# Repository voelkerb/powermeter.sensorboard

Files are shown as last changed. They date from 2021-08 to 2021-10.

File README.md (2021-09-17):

[PowerMeter]: (https://github.com/voelkerb/powermeter)
[bopla]:(https://www.conrad.de/de/p/bopla-eletec-se-432-de-cee-stecker-gehaeuse-120-x-65-x-50-abs-polycarbonat-lichtgrau-graphitgrau-1-st-522228.html)

# powermeter.sensorboard
Expansion board for the [PowerMeter] including multiple environmental sensors, LEDs, and a push button.

The [PowerMeter] includes an extension header that exposes the ESP32's UART interface.
This interface can be used to add more environmental sensors to a [PowerMeter].
The developed sensor board can be stacked on the [PowerMeter] _PCB_ and the embedded sensors may be exposed to the outside of the housing. 
See the following example:

<p align="center">
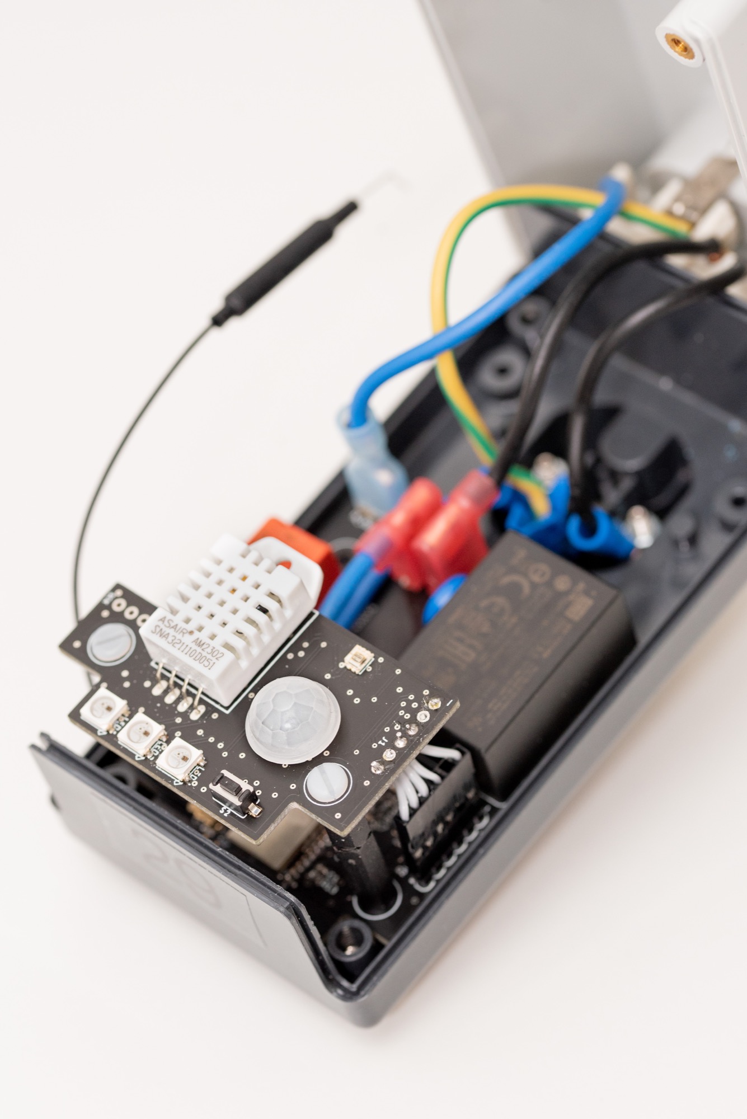
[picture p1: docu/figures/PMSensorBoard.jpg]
  
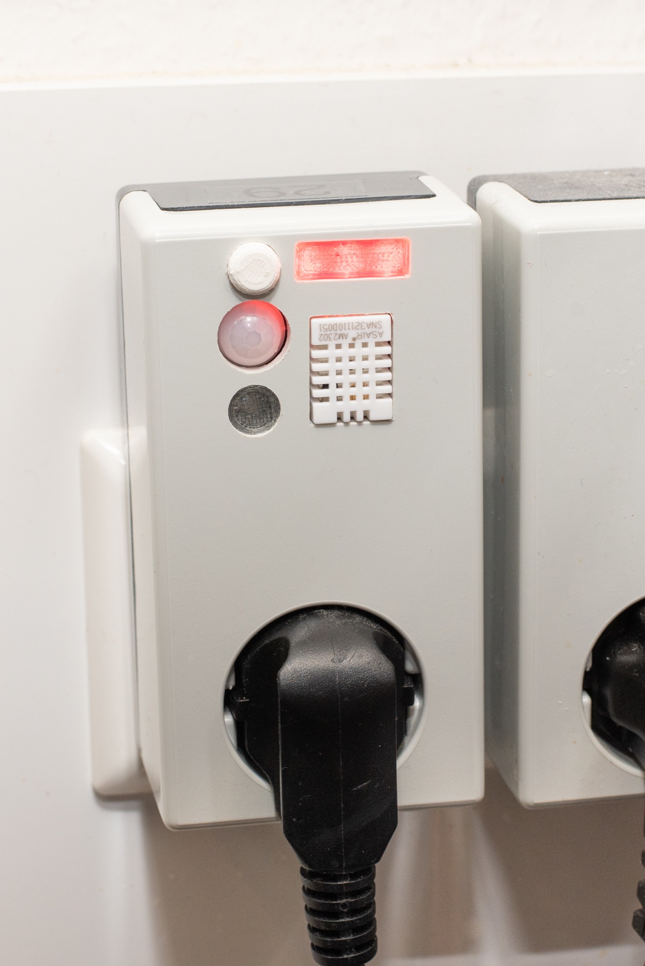
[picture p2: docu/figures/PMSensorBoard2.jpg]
  
</p>

---

## Sensors
The board incorporates typical environmental sensors:
A DHT22 for temperature and humidity readings, a TSL2561 light sensor and PIR sensor to detect people's movements. 

## Feedback
For visual feedback, three WS2812B RGB LEDs are included. These can automatically visualize the current energy consumption via color (_eco-feedback_) or indicate states or errors via patterns.   

## Interfacing
The incorporated button allows to switch the [PowerMeter] relay. If you require other functionality, these can be added via double-press or long-press gestures as well.

## Housing
The housing is a modified version of the [bopla] housing used for the [PowerMeter]. You can either cut in holes or 3D print a version with corresponding cutouts and holders for the sensor board. The 3D files also include the button and a light sensor and LED cover which should be printed with transparent filament.

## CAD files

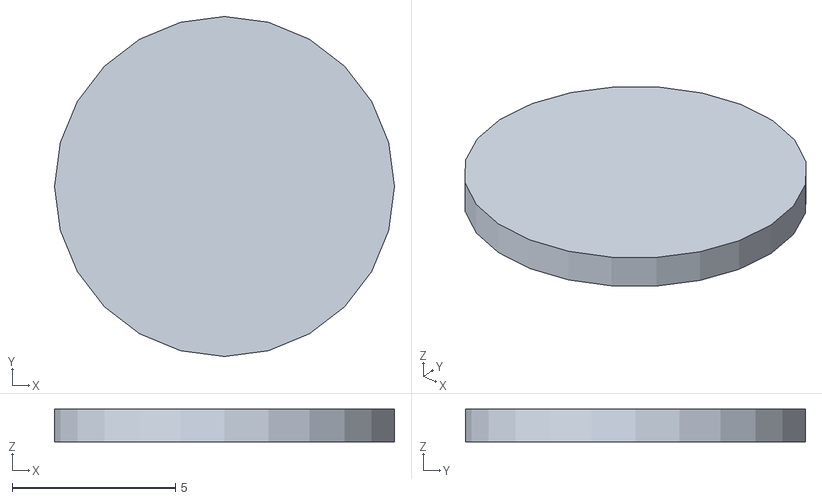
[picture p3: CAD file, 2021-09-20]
CAD/coverLight.stl
10.4 x 10.4 x 1

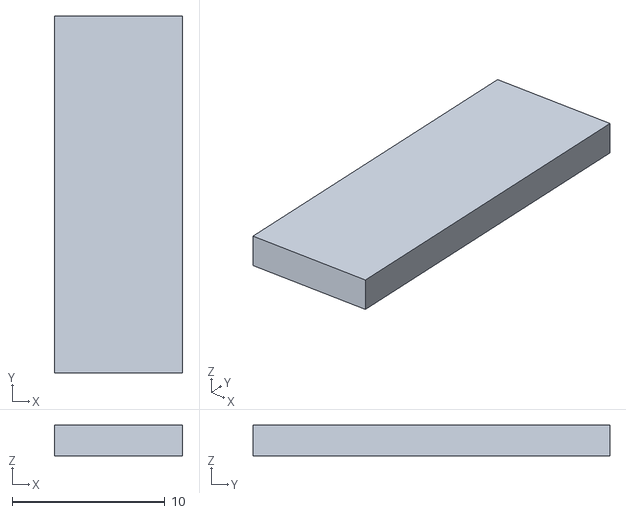
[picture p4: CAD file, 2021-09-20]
CAD/coverLED.stl
8.40 x 23.4 x 2.00

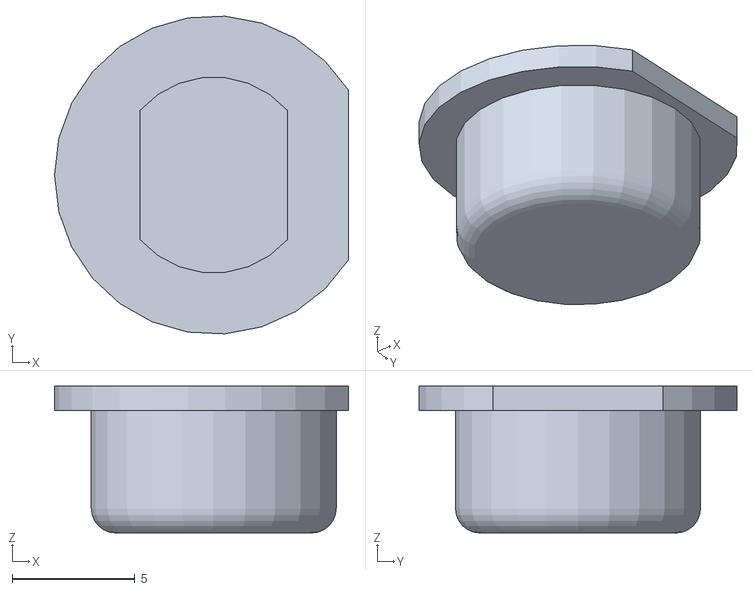
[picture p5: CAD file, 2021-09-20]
CAD/button.stl
12.0 x 13.0 x 6.00

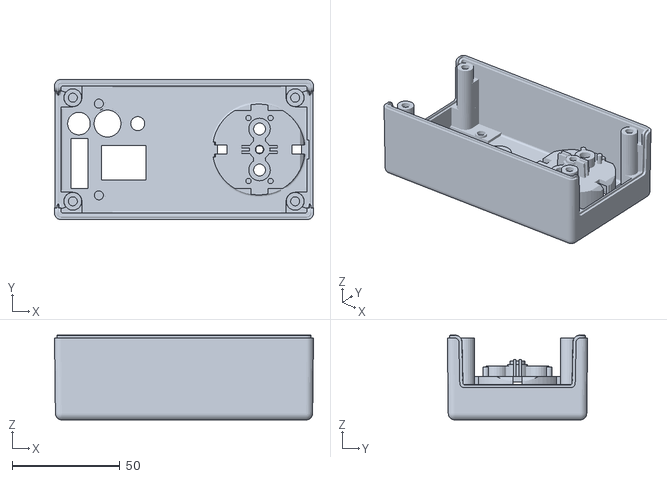
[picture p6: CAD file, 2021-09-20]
CAD/housingTop.stl
120.0 x 65.0 x 39.3

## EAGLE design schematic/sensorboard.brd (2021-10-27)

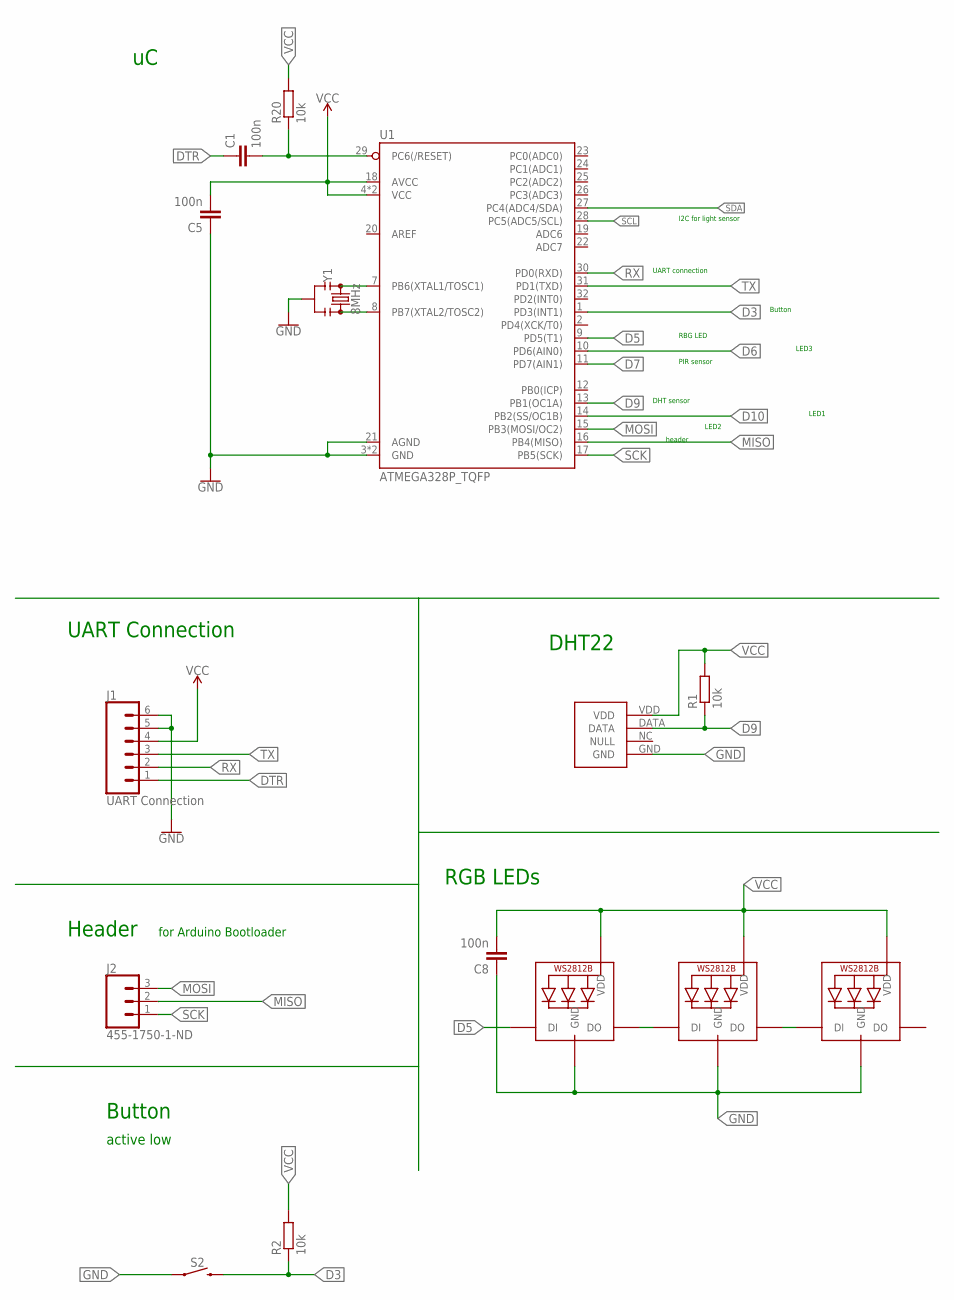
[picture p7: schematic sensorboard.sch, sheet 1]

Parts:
C1, C5, C8: 100n; C0402
DHT22: DHT22
J1: UART Connection; 1X06
J2: 455-1750-1-ND; 1X03
LED1, LED2, LED3: WS2812B5050; WS2812B
R1, R2, R20: 10k; R0402
S2: MOMENTARY-SWITCH-SPST-SMD-6.0X3.5MM; TACTILE_SWITCH_SMD_6.0X3.5MM
U1: ATMEGA328P_TQFP; TQFP32-08
Y1: 8MHz; RESONATOR-SMD-3.2X1.3

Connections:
D3: R2.1, S2.2, U1.1 (PD3(INT1))
D5: LED2.4-DIN (DI), U1.9 (PD5(T1))
D6: U1.10 (PD6(AIN0)); also elsewhere on the board
D7: U1.11 (PD7(AIN1)); also elsewhere on the board
D9: DHT22.DATA, R1.1, U1.13 (PB1(OC1A))
D10: U1.14 (PB2(SS/OC1B)); also elsewhere on the board
DTR: C1.1, J1.1
GND: C5.1, C8.1, DHT22.GND, J1.5, J1.6, LED1.3-GND (GND), LED2.3-GND (GND), LED3.3-GND (GND), S2.1, U1.3 (GND), U1.5 (GND), U1.21 (AGND), Y1.2; also elsewhere on the board
MISO: J2.2, U1.16 (PB4(MISO))
MOSI: J2.3, U1.15 (PB3(MOSI/OC2)); also elsewhere on the board
unnamed: U1.7 (PB6(XTAL1/TOSC1)), Y1.1
unnamed: U1.8 (PB7(XTAL2/TOSC2)), Y1.3
unnamed: LED1.4-DIN (DI), LED2.2-DOUT (DO)
unnamed: LED1.2-DOUT (DO), LED3.4-DIN (DI)
unnamed: C1.2, R20.1, U1.29 (PC6(/RESET))
RX: J1.2, U1.30 (PD0(RXD))
SCK: J2.1, U1.17 (PB5(SCK))
SCL: U1.28 (PC5(ADC5/SCL)); also elsewhere on the board
SDA: U1.27 (PC4(ADC4/SDA)); also elsewhere on the board
TX: J1.3, U1.31 (PD1(TXD))
VCC: C5.2, C8.2, DHT22.VDD, J1.4, LED1.1-VDD (VDD), LED2.1-VDD (VDD), LED3.1-VDD (VDD), R1.2, R2.2, R20.2, U1.4 (VCC), U1.6 (VCC), U1.18 (AVCC); also elsewhere on the board

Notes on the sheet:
DHT22
UART Connection
Button
DHT sensor
I2C for light sensor
PIR sensor
active low
Header
for Arduino Bootloader
LED1
LED2
LED3
UART connection
header
RBG LED
RGB LEDs

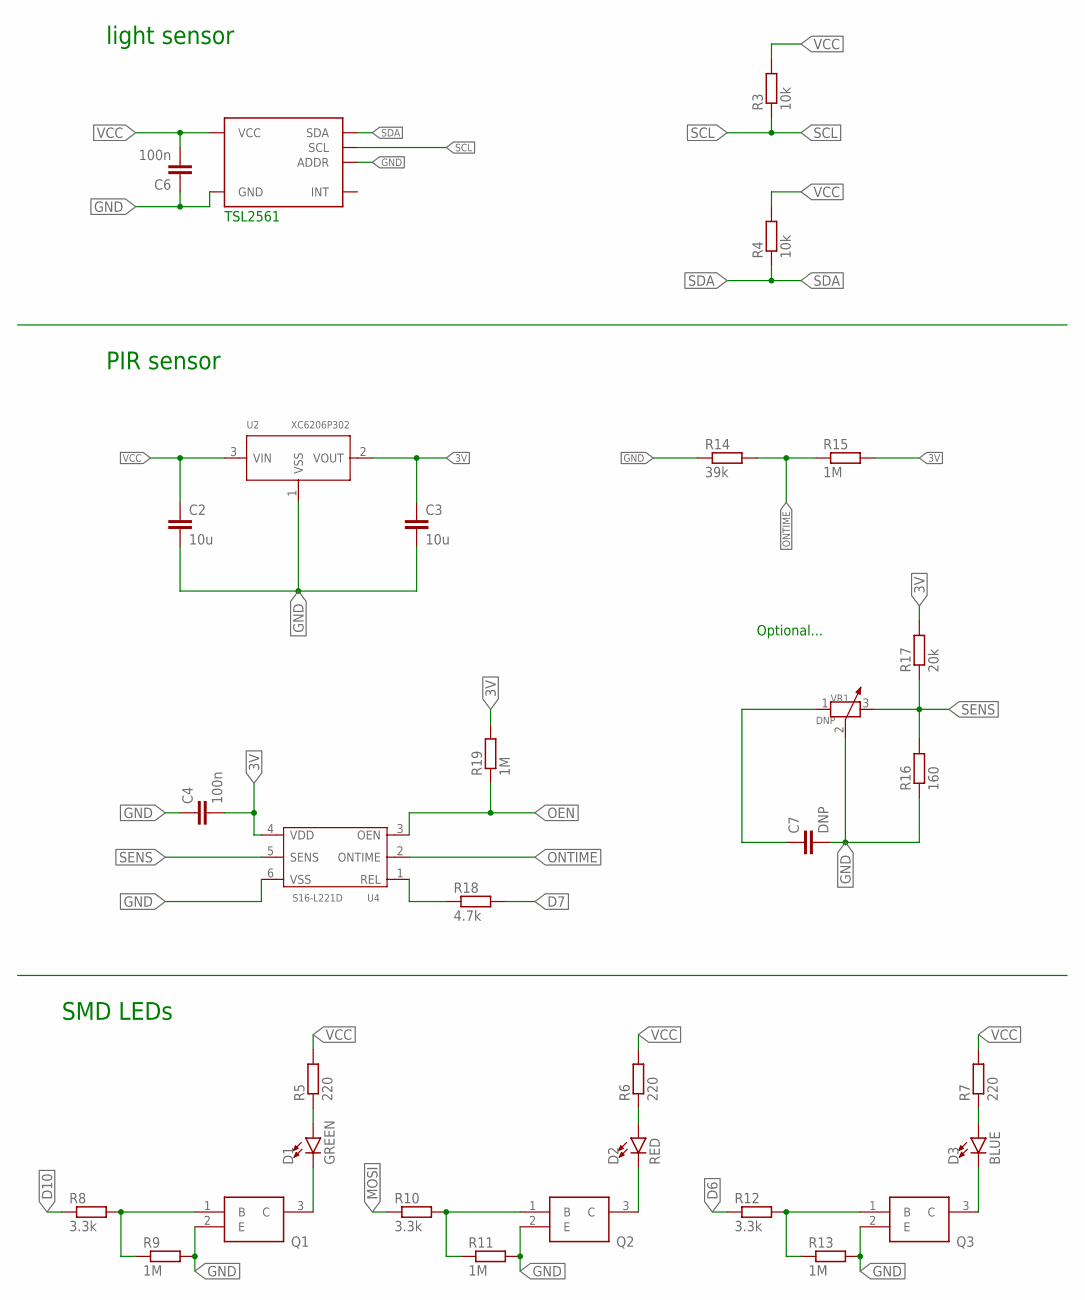
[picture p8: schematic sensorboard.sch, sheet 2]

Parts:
C2, C3: 10u; C0402
C4, C6: 100n; C0402
C7: DNP; C0402
D1: GREEN; LED-0603
D2: RED; LED-0603
D3: BLUE; LED-0603
Q1, Q2, Q3: MMSS8050-L-TP; SOT96P237X122-3N
R3, R4: 10k; R0402
R5, R6, R7: 220; R0402
R8, R10, R12: 3.3k; R0402
R9, R11, R13, R15, R19: 1M; R0402
R14: 39k; R0402
R16: 160; R0402
R17: 20k; R0402
R18: 4.7k; R0402
TSL2561: TSL2561FN; DFN-6
U2: XC6206P302; SOT-23
U4: S16-L221D; 6P-SMD-6X6MM
VR1: DNP; ADJR3-SMD-4.6X3.7MM

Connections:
3V: C3.1, C4.2, R15.2, R17.2, R19.2, U2.2 (VOUT), U4.4 (VDD)
D6: R12.1; also elsewhere on the board
D7: R18.2; also elsewhere on the board
D10: R8.1; also elsewhere on the board
GND: C2.2, C3.2, C4.1, C6.1, C7.2, Q1.2 (E), Q2.2 (E), Q3.2 (E), R9.2, R11.2, R13.2, R14.1, R16.1, TSL2561.ADDR, TSL2561.GND, U2.1 (VSS), U4.6 (VSS), VR1.2 (3); also elsewhere on the board
MOSI: R10.1; also elsewhere on the board
unnamed: R18.1, U4.1 (REL)
unnamed: C7.1, VR1.1
unnamed: D1.C, Q1.3 (C)
unnamed: Q1.1 (B), R8.2, R9.1
unnamed: Q2.1 (B), R10.2, R11.1
unnamed: Q3.1 (B), R12.2, R13.1
unnamed: D1.A, R5.1
unnamed: D2.C, Q2.3 (C)
unnamed: D2.A, R6.1
unnamed: D3.A, R7.1
unnamed: D3.C, Q3.3 (C)
OEN: R19.1, U4.3 (OEN)
ONTIME: R14.2, R15.1, U4.2 (ONTIME)
SCL: R3.1, TSL2561.SCL; also elsewhere on the board
SDA: R4.1, TSL2561.SDA; also elsewhere on the board
SENS: R16.2, R17.1, U4.5 (SENS), VR1.3 (2)
VCC: C2.1, C6.2, R3.2, R4.2, R5.2, R6.2, R7.2, TSL2561.VDD (VCC), U2.3 (VIN); also elsewhere on the board

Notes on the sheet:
light sensor
PIR sensor
TSL2561
Optional...
SMD LEDs

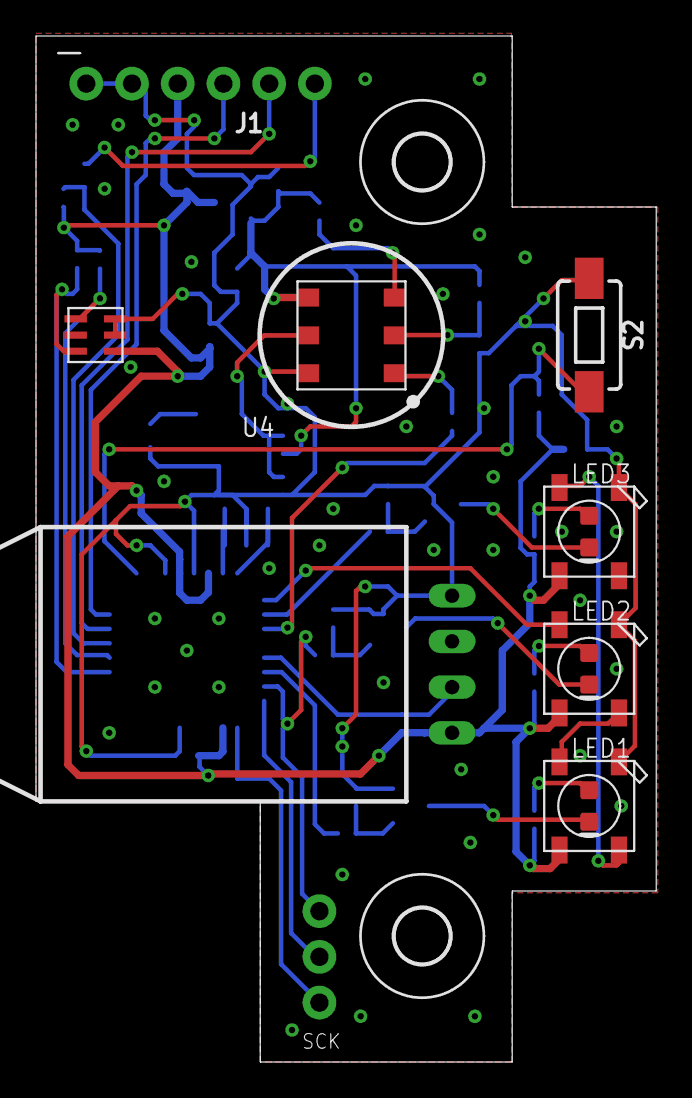
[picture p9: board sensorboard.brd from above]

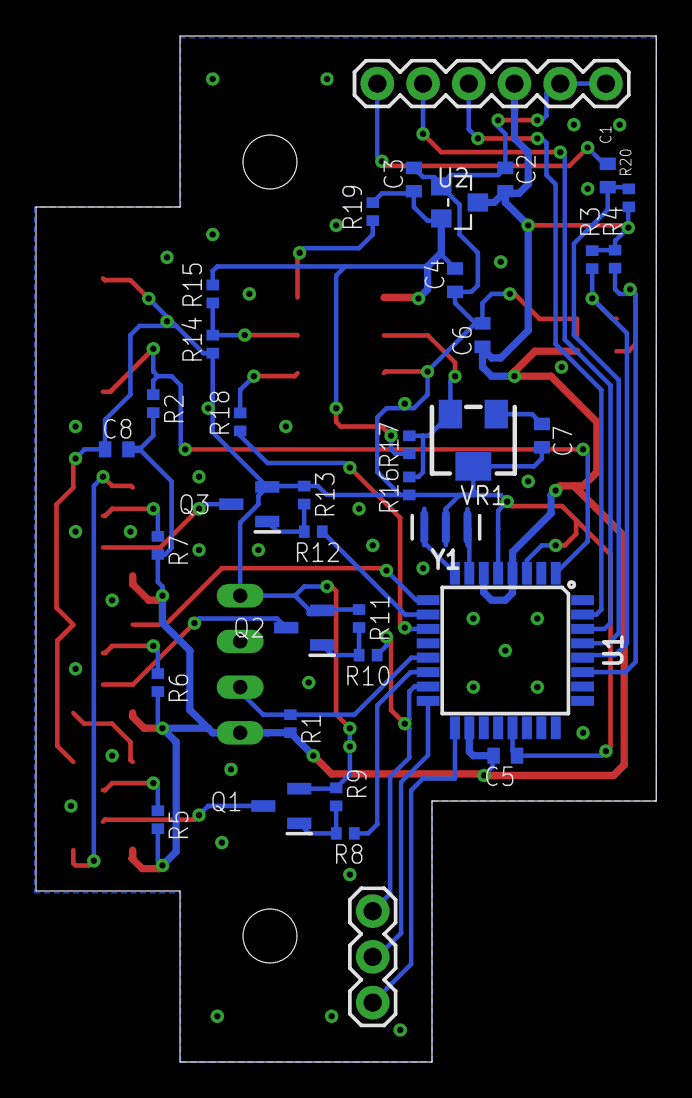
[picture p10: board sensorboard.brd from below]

Board: 2 copper layers, 34.5 x 57.0 mm, 49 parts (37 on the bottom side), 36 nets.

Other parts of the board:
U$1, U$2: 3,0

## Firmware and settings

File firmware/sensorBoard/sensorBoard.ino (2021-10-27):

// Arduino ATMEGA328 8MHz Sketch with Sensors: DHT 11, Grove Button, LED WS2812b Light Sensor and PIR Sensor

// #include <ArduinoJson.h>
// #include <stdio.h>
// #include <string>

// sensor libraries
#include <FastLED.h>
#include <DHT.h>
#include <Wire.h>
#include <Digital_Light_TSL2561.h>
#include <SoftwareSerial.h>
#include <EEPROM.h>

// Choose one of the following
// Either you get press and release 
// #define STATEFULL_PRESS
// Or you get Single press, double press, long press etc.


// SoftwareSerial softSerial(10,11);

#if defined(ESP8266)
void ICACHE_RAM_ATTR buttonISR();
#endif
enum class BUTTON_PRESS {NONE=0, SINGLE=1, DOUBLE=2, LONG_START=3, RELEASE=4};
void buttonPressed(BUTTON_PRESS press);
// pins
#define LED_PIN 5
#define PIR_PIN 7
#define DHT_PIN 9
// TODO
#if defined(ESP8266)
#define BUTTON_PIN D6
#else 
#define BUTTON_PIN 3
#endif

#define BRIGHTNESS_ADDRESS 0

// Serial stuff
#define SERIAL_SPEED 38400
// #define DEBUG
// #define USE_ASCI_INT
#define USE_SENSORS

#define debugSerial Serial
#define com Serial

// LED
// Define the array of leds
#define NUM_LEDS 3
CRGB leds[NUM_LEDS];
CRGB fadeColor[NUM_LEDS];
CRGB black = CRGB::Black;
bool ledUpdate = false;

//DHT
#ifdef USE_SENSORS
DHT dht(DHT_PIN, DHT22);
#endif
// automaticall send data on change and with hysteresis
bool autoSend = false;

// old values for sensors
float temp = -1;
float hum = -1;
int32_t light = -1;
uint8_t pir = 255;

uint8_t brightness = 255;

// Update timers
long lightUpdate = millis();
long tempUpdate = millis();
long humUpdate = millis();
#define LIGHT_UPDATE_INTV 5000
#define TEMP_UPDATE_INTV 5000
#define HUM_UPDATE_INTV TEMP_UPDATE_INTV // as it is from the same sensor

uint8_t fadeDelay = 5;

#define DOUBLE_PRESS_DELAY 900
#define LONG_PRESS_DELAY 5000
// Button pressed flag handled in loop
bool buttonReleased = false;
volatile int pressed = 0;
volatile long lastPressed = millis();

volatile bool oldState = false;
volatile long lastTime = millis();

#ifdef STATEFULL_PRESS
void handleButton() {
  if (pressed != 0) {
    BUTTON_PRESS buttonPress = BUTTON_PRESS::NONE;
    // Button was already long pressed and is now released
    if (pressed == -1 and buttonReleased) {
      buttonPress = BUTTON_PRESS::RELEASE;
      pressed = 0;
    // Button has been pressed
    } else if (pressed > 0) {
      // Button has been released and doublepress detection time has passed
      if (buttonReleased and millis()-lastPressed > DOUBLE_PRESS_DELAY) {
        // number stored in pressed corresponds to the number of presses
        if (pressed == 1) {
          buttonPress = BUTTON_PRESS::SINGLE;
        } else if (pressed == 2) {
          buttonPress = BUTTON_PRESS::DOUBLE;
        } else {
          // Treet as single press
          buttonPress = BUTTON_PRESS::SINGLE;
        }
        // Reset variable
        pressed = 0;
      // Button not yet released but long press delay already passed
      } else if (!buttonReleased and millis()-lastPressed > LONG_PRESS_DELAY) {
        // If long press start not indicated yet
        if (pressed != -1) {
          buttonPress = BUTTON_PRESS::LONG_START;
          pressed = -1;
        } 
      }  
    }
    if (buttonPress != BUTTON_PRESS::NONE) buttonPressed(buttonPress);
  }
}

void buttonPressed(BUTTON_PRESS press) {
  switch (press) {
    case BUTTON_PRESS::NONE:
      break;
    case BUTTON_PRESS::SINGLE:
      #ifdef DEBUG
      debugSerial.println("Single press");
      #endif
      com.println("!b1");
      break;
    case BUTTON_PRESS::DOUBLE:
      #ifdef DEBUG  
      debugSerial.println("Double press");
      #endif
      com.println("!b2");
      break;
    case BUTTON_PRESS::LONG_START:
      #ifdef DEBUG
      debugSerial.println("Long press start");
      #endif
      com.println("!b3");
      break;
    case BUTTON_PRESS::RELEASE:
      #ifdef DEBUG
      debugSerial.println("Long press end");
      #endif
      com.println("!b4");
      break;
    default:
      break;
  }
}

#if defined(ESP8266)
void ICACHE_RAM_ATTR buttonISR() {
#else
void buttonISR() {
#endif
  bool state = !digitalRead(BUTTON_PIN);
  if (state == oldState) return;
  // Debounce delay
  if (millis()-lastTime < 10) return;
  lastTime = millis();
  if (state) {
    #ifdef DEBUG
    debugSerial.println("Pressed");
    #endif
    pressed++;
    lastPressed = millis();
    buttonReleased = false;
  } else {
    #ifdef DEBUG
    debugSerial.println("Released");
    #endif
    buttonReleased = true;
  }
  oldState = state;
}

#else 
#if defined(ESP8266)
void ICACHE_RAM_ATTR buttonISR() {
#else
void buttonISR() {
#endif
  bool state = !digitalRead(BUTTON_PIN);
  if (state == oldState) return;
  // Debounce delay
  if (millis()-lastTime < 10) return;
  lastTime = millis();
  if (state) {
    #ifdef DEBUG
    debugSerial.println("Pressed");
    #endif
    com.println("!b");
  } else {
    #ifdef DEBUG
    debugSerial.println("Released");
    #endif
    com.println("!r");
  }
  oldState = state;
}
#endif

void setup() {
  // Init serial
  com.begin(SERIAL_SPEED);
  #ifdef DEBUG
  #if debugSerial != com
  debugSerial.begin(SERIAL_SPEED);
  #endif
  #endif

  #ifdef DEBUG
  debugSerial.println("Setup init");
  #endif

  // Init LEDs
  FastLED.addLeds<WS2812B, LED_PIN, GRB>(leds, NUM_LEDS); 
  // Tests LEDs
  setAllLEDs(CRGB::Red);
  delay(100);
  setAllLEDs(CRGB::Green);
  delay(100);
  setAllLEDs(CRGB::Blue);
  delay(100);
  setAllLEDs(CRGB::Black);
  // allLEDs(fadeColor, NUM_LEDS, black);
  // // Fade black
  // ledUpdate = true;
  #if defined(ESP8266)
  EEPROM.begin(512);
  #endif
  // Load and set brightness
  EEPROM.get(BRIGHTNESS_ADDRESS, brightness);
  FastLED.setBrightness(brightness);
  // Set button as input and configure pin interrupt
  pinMode(BUTTON_PIN, INPUT_PULLUP);
  attachInterrupt(digitalPinToInterrupt(BUTTON_PIN), buttonISR, CHANGE); 
  #ifdef USE_SENSORS
  // PIR has digital input signal
  #ifdef DEBUG
  debugSerial.println("PIR init");
  pinMode(PIR_PIN, INPUT_PULLUP);
  #endif
  // Wire required for TSL
  Wire.begin();
  #ifdef DEBUG
  debugSerial.println("DHT init");
  #endif
  bool success = true;
  dht.begin();
  float te = dht.readTemperature();
  if (te >= 0 && te < 100) success &= true;
  else success = false;
  #ifdef DEBUG
  debugSerial.println("TSL2561 init");
  #endif
  TSL2561.init();
  int val = TSL2561.readVisibleLux();
  if (val >= 0 && val < 10000) success &= true;
  else success = false;
  
  #endif
  
  while (com.available()) com.read();
  if (success) {
    setAllLEDs(CRGB::Green);
  } else {
    setAllLEDs(CRGB::Red);
  }
  delay(50);
  allLEDs(fadeColor, NUM_LEDS, black);
  // // Fade black
  ledUpdate = true;
  #ifdef DEBUG
  debugSerial.println("Setup done!");
  #endif

  delay(50);
  allLEDs(fadeColor, NUM_LEDS, black); 
}



void loop() {
  #ifdef STATEFULL_PRESS
  handleButton();
  #endif
  // recieve command from powermeter
  if (com.available()) {
    // No sensor updates on flood requests
    handleEvent();
    return;
  }
  #ifdef USE_SENSORS
  if (autoSend) {
    sendPIR(true);
    if (millis()-lightUpdate > LIGHT_UPDATE_INTV) {
      lightUpdate = millis();
      sendLight(true);
    }
    if (millis()-humUpdate > HUM_UPDATE_INTV) {
      humUpdate = millis();
      sendHum(true);
    }
    if (millis()-tempUpdate > TEMP_UPDATE_INTV) {
      tempUpdate = millis();
      sendTemp(true);
    }
  }
  #endif
  // As long as fade is not finished, continue fading
  if (ledUpdate) {
    ledUpdate = !fadeit();
    FastLED.show();
    // Becomes slightly irresponsive on LED updates
    FastLED.delay(fadeDelay); 
  }
}


void handleEvent() {
  if (!(com.available()>2)) return;
  char c = com.read();
  // If it is not a !, return
  if (c != '?' and c != '!') return;
  // Let all data be sent by the sink
  delay(2);
  char d = com.read();
  switch (d) {
    case '?':
      com.println("!!");
      break;
    case 'b':
      #ifdef USE_ASCI_INT
      brightness = com.parseInt();
      #else
      brightness = com.read();
      #endif
      EEPROM.put(BRIGHTNESS_ADDRESS, brightness);
      FastLED.setBrightness(brightness);
      FastLED.show();
      #ifdef DEBUG
      debugSerial.print("Set brightess to: ");
      EEPROM.get(BRIGHTNESS_ADDRESS, brightness);
      debugSerial.println(brightness);
      #endif
      break;
    case 'a':
      autoSend = true;
      //  New values on next run
      lightUpdate = millis()-LIGHT_UPDATE_INTV;
      humUpdate = millis()-HUM_UPDATE_INTV;
      tempUpdate = millis()-TEMP_UPDATE_INTV;
      temp = -1;
      hum = -1;
      light = -1;
      pir = 255;
      #ifdef DEBUG
      debugSerial.println("Autosend on");
      #endif
      break;
    case 'o':
      autoSend = false;
      #ifdef DEBUG
      debugSerial.println("Autosend off");
      #endif
      break;
    #ifdef USE_SENSORS
    case 'p':
      sendPIR(false);
      #ifdef DEBUG
      debugSerial.print("PIR send: ");
      debugSerial.println(pir);
      #endif
      break;
    case 't':
      sendTemp(false);
      #ifdef DEBUG
      debugSerial.print("Temp send: ");
      debugSerial.println(temp);
      #endif
      break;
    case 'h':
      sendHum(false);
      #ifdef DEBUG
      debugSerial.print("HUM send: ");
      debugSerial.println(hum);
      #endif
      break;
    case 'l':
      sendLight(false);
      #ifdef DEBUG
      debugSerial.print("Light send: ");
      debugSerial.println(light);
      #endif
      break;
    #endif
    case 'L':
      delay(10);
      if (com.available() < 3*NUM_LEDS) return;
      #ifdef USE_ASCI_INT
      for (int i = 0; i < NUM_LEDS; i++) {
        uint8_t r = com.parseInt();
        uint8_t g = com.parseInt();
        uint8_t b = com.parseInt();
        fadeColor[i] = CRGB(r,g,b);
      }
      #else
      for (int i = 0; i < NUM_LEDS; i++) {
        uint8_t r = com.read();
        uint8_t g = com.read();
        uint8_t b = com.read();
        fadeColor[i] = CRGB(r,g,b);
      }
      #endif
      // Will only get \n
      if (com.available() and com.read() == 'f') {
        ledUpdate = true;
      } else {
        for (int i = 0; i < NUM_LEDS; i++) leds[i] = fadeColor[i];
        FastLED.show();
      }
      #ifdef DEBUG
      debugSerial.print("Set LED to: ");
      for (int i = 0; i < NUM_LEDS; i++) {
        debugSerial.print("[");
        debugSerial.print(fadeColor[i].red);
        debugSerial.print(",");
        debugSerial.print(fadeColor[i].green);
        debugSerial.print(",");
        debugSerial.print(fadeColor[i].blue);
        debugSerial.print("] ");
      }
      debugSerial.println();
      #endif
      break;
    default:
      #ifdef DEBUG
      debugSerial.println("Unknown command");
      #endif
      break;
  }
  // Wait for remaining data
  if (!com.available()) delay(1);
  // Wait for \n
  while (com.available() and com.read() != '\n') {};
}

#ifdef USE_SENSORS
void sendPIR(bool onNew) {
  uint8_t newPIR = (uint8_t)digitalRead(PIR_PIN);
  if (onNew and newPIR == pir) return;
  pir = newPIR;
  com.print("!p");
  com.write(pir);
  com.println();
}

void sendTemp(bool onNew) {
  float newTemp = (float)dht.readTemperature();
  //  Measurement error
  if (newTemp == -1) {
    if (!onNew) newTemp = temp;
    else return;
  }
  if (onNew and newTemp == temp) return;
  temp = newTemp;
  byte * b = (byte *) &temp;
  com.print("!t");
  com.write(b,4);
  com.println();
}

void sendHum(bool onNew) {
  float newHum = (float)dht.readHumidity();
  //  Measurement error
  if (newHum == -1) {
    if (!onNew) newHum = hum;
    else return;
  }
  if (onNew and newHum == hum) return;
  hum = newHum;
  byte * b = (byte *) &hum;
  com.print("!h");
  com.write(b,4);
  com.println();
}

void sendLight(bool onNew) {
  uint32_t newLight = (uint32_t)TSL2561.readVisibleLux();
  if (onNew and newLight == light) return;
  light = newLight;
  byte * b = (byte *) &light;
  com.print("!l");
  com.write(b,4);
  com.println();
}
#endif

void allLEDs(CRGB *colors, uint32_t N, CRGB color) {
  for (int i = 0; i < N; i++) colors[i] = color;
}

void setAllLEDs(CRGB color) {
  allLEDs(leds, NUM_LEDS, color);
  FastLED.show();
}

bool fadeit() {
  for( uint16_t i = 0; i < NUM_LEDS; i++) {
    fadeTowardColor(leds[i], fadeColor[i], 10);
  }
  // Check if now done
  bool allDone = true;
  for (int i = 0; i < NUM_LEDS; i++) {
    if (leds[i] != fadeColor[i]) {
      allDone = false;
      break;
    }
  }
  return allDone;
}


// Helper function that blends one uint8_t toward another by a given amount
void nblendU8TowardU8(uint8_t& cur, const uint8_t target, uint8_t amount) {
  if (cur == target) return;
  if (cur < target) {
    uint8_t delta = target - cur;
    delta = scale8_video( delta, amount);
    cur += delta;
  } else {
    uint8_t delta = cur - target;
    delta = scale8_video( delta, amount);
    cur -= delta;
  }
}

// Blend one CRGB color toward another CRGB color by a given amount.
// Blending is linear, and done in the RGB color space.
// This function modifies 'cur' in place.
CRGB fadeTowardColor(CRGB& cur, const CRGB& target, uint8_t amount) {
  nblendU8TowardU8(cur.red,   target.red,   amount);
  nblendU8TowardU8(cur.green, target.green, amount);
  nblendU8TowardU8(cur.blue,  target.blue,  amount);
  return cur;
}

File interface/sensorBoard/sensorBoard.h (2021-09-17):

/***************************************************
 Library for SensorBoard

 Feel free to use the code as it is.

 Benjamin Voelker, voelkerb@me.com
 Embedded Systems
 University of Freiburg, Institute of Computer Science
 ****************************************************/

#ifndef SENSORBOARD_h
#define SENSORBOARD_h


#if (ARDUINO >= 100)
#include "Arduino.h"
#else
#include "WProgram.h"
#endif


#define NUM_LEDS 3
enum class LED_MODE {MANUAL = 0, POWER = 1};
enum class NEW_SENSOR_VALUE {NONE = 0, NEW_BTN = 1, NEW_TEMP = 2, NEW_HUM = 3, NEW_LIGHT = 4, NEW_PIR = 5, ACTIVE = 6, UNKNOWN = 6};
enum class BUTTON_PRESS {NONE=0, SINGLE=1, DOUBLE=2, LONG_START=3, RELEASE=4, PRESS=5};

enum class LEDPattern {
  staticPattern = 0,
  blinkPattern = 1,
  roundPattern = 2,
  glowPattern = 3,
  activePowerPattern = 4,
  numberOfPatterns = 5
};

struct __attribute__((__packed__)) SensorBoardConfiguration {
  float tempOffset = 0.0; 
  float humOffset = 0.0; 
  float brightness = 1.0;
  float lightCal = 1.0;
  float minLEDWatt = 2.0;
  float maxLEDWatt = 200.0;
};

// CRGB Struct
struct CRGB {
  union {
		struct {
      union {
        uint8_t r;
        uint8_t red;
      };
      union {
        uint8_t g;
        uint8_t green;
      };
      union {
        uint8_t b;
        uint8_t blue;
      };
    };
    uint8_t raw[3];
  };
};

// Some easy defined colors
#define COLOR_BLACK CRGB{0,0,0}
#define COLOR_GREY CRGB{64,64,64}
#define COLOR_RED CRGB{255,0,0}
#define COLOR_GREEN CRGB{0,255,0}
#define COLOR_BLUE CRGB{0,0,255}
#define COLOR_ORANGE CRGB{255,255,0}
#define COLOR_PINK CRGB{255,0,255}

/// Test two CRGB for equality
inline __attribute__((always_inline)) bool operator== (const CRGB& lhs, const CRGB& rhs) { return (lhs.r == rhs.r) && (lhs.g == rhs.g) && (lhs.b == rhs.b); }
inline __attribute__((always_inline)) bool operator!= (const CRGB& lhs, const CRGB& rhs) { return !(lhs == rhs); }

class SensorBoard {
  #define SENSOR_WAIT_TIME 1000
  
  public:
    SensorBoard(
        Stream * getter, 
        float tempHysteresis, float humHysteresis, int lightHysteresis, float minLEDWatt, float maxLEDWatt,
        // void (*loadStoreFunc)(bool store, uint8_t *data, size_t size)=NULL,
        void (*logFunc)(const char * msg, ...)=NULL
      );
    bool init();

    // Update LEDs and Serial communication
    void update();
    // Update sensors
    bool updateSensors(bool wait=false);
    bool updateLight(bool wait=false);
    bool updateTemp(bool wait=false);
    bool updateHum(bool wait=false);
    bool updatePIR(bool wait=false);
    void setAutoSensorMode(bool on);
    // Handle serial connection
    enum NEW_SENSOR_VALUE handle(int timeout=-1);

    void setBrightness(float brightness);
    // Set new LED pattern
    void newLEDPattern(LEDPattern pattern, long duration, CRGB theFGColor, CRGB theBGColor);
    // Easy wrappers
    void setRainbow(long duration=-1);
    void setDots(int dots, CRGB color, CRGB bgColor=COLOR_BLACK, long duration=-1);
    void setDots(int dots, CRGB color, long duration);
    void displayPowerColor(long duration=-1);
    void setIndividualColors(CRGB *colors, size_t n, bool fade=false, long duration=-1);
    void setColor(CRGB color, bool fade);
    void setColor(CRGB color, int duration);
    void setColor(CRGB color, long duration);
    void setColor(CRGB color, long duration=-1, bool fade=false);
    void glow(CRGB color, CRGB bgColor=COLOR_BLACK, long duration=-1);
    void glow(CRGB color, long duration);
    void blink(CRGB color, CRGB bgColor=COLOR_BLACK, long duration=-1);
    void blink(CRGB color, long duration);

    float humidity;
    float temperature;
    bool PIR;
    int light;
    bool active;
    bool autoMode;

    void (*buttonCB)(BUTTON_PRESS);
    void (*tempCB)(float);
    void (*humCB)(float);
    void (*lightCB)(uint32_t);
    void (*PIRCB)(bool);
    float (*activePowerGetter)(void);

    SensorBoardConfiguration config;

  private:

    float _tempHysteresis;
    float _humHysteresis;
    int _lightHysteresis;
    // LED array
    CRGB LED[NUM_LEDS];
    // Setting all LEDs to same color
    void allLEDs(CRGB c);
    void setAllLEDs(CRGB c);
    // Update the led array
    void updateLEDs();

    // pattern states
    #define INIT_PATTERN -1
    #define GLOW_UP 0
    #define GLOW_DOWN 1
    #define BLINK_ONE 0
    #define BLINK_TWO 1
    #define ROUND_ONE 0
    #define ROUND_TWO 1

    // Speeds for pattern updates in ms
    #define GLOW_STEP 50
    #define BLINK_STEP 500
    #define ROUND_STEP 200
    #define ACTIVE_POWER_UPDATE 5000

    // Array holding helper functions
    typedef void (* PatternFunction)(SensorBoard *obj);
    PatternFunction updatePattern[(int)LEDPattern::numberOfPatterns];
    // Array holding update times
    unsigned int patternUpdateTimes[(int)LEDPattern::numberOfPatterns];
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

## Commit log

2021-08-19 added support for statefull button
2021-08-19 powerToLEDs update automatically
2021-08-19 itnerface now includes LED patterns
2021-08-26 successfull sensor init displayed by LEDs
2021-09-17 added design files
    [Button.stl, HousingTop.stl, LEDCover.stl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]
2021-09-17 added housing comments
2021-09-20 new cad files
    [button.stl, coverLED.stl, coverLight.stl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]
2021-09-20 new CAD
    [button.stl, coverLED.stl, coverLight.stl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]
2021-10-27 added more debug options
    [sensorboard.brd, sensorboard.sch]
2022-10-28 Fix for invalid sensor board configs Maybe in a next iteration we set all to default if one is corrupt.

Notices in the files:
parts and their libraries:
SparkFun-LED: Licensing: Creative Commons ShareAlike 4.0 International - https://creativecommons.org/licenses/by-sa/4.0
